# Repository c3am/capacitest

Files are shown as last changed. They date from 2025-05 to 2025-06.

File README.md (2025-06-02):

# capacitest
A low cost dual cell battery capacity tester with an oled screen using the ch32v003 microcontroller.

# discharge-tester (old version, unfinished)
In the discharge-tester directory is a pcb with mosfets used as variable resistors for discharging the cells.
It uses LMV358's as current sense amplifiers across 1 Ohm current sense resistors.
I did not get this setup to work, because the built-in adc gave me very jittery values.
Maybe there is something wrong with my circuit, or you just have to software filter the adc values.

# bidirectional-tester (current version, under development)
This is the newer version, which uses bidirectional buck-boost converters for charging the cells from an external ~12V battery/discharging them into that battery.

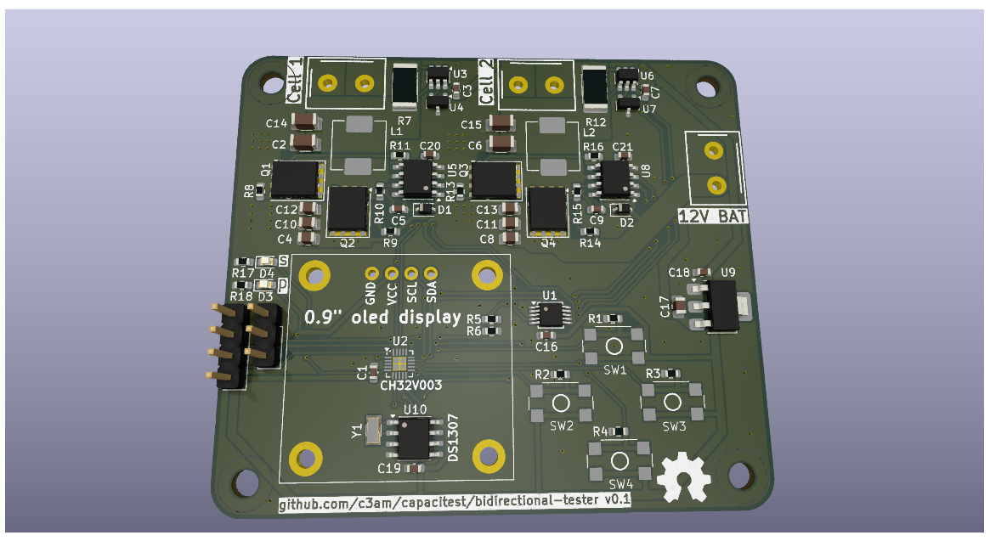
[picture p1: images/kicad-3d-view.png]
kicad 3d view of bidirectional tester


- ADS 1115 for current and voltage sensing
- ina181a2 + ref2020(2V Vref) for current sense amplification
- ir2101 low+high side mosfet drivers
- ceramic capacitors only
- the two bidirectional buck-/boost-converters each have 1uH SMD inductors, 200uF on the cell and 66uF capacitance on the ~12V battery side
- 0.9" i2c oled screen

## development status/roadmap:
| step | status |
| --- | --- |
| schematic design | [done] |
| PCB design | [done] |
| get PCB and other components  | [done] |
| assemble board | [...] |
| test board/write code | [not started] |
| if not working, repeat | |
| finalize code and put online  | [not started] |

(last updated: 2025-05-08)

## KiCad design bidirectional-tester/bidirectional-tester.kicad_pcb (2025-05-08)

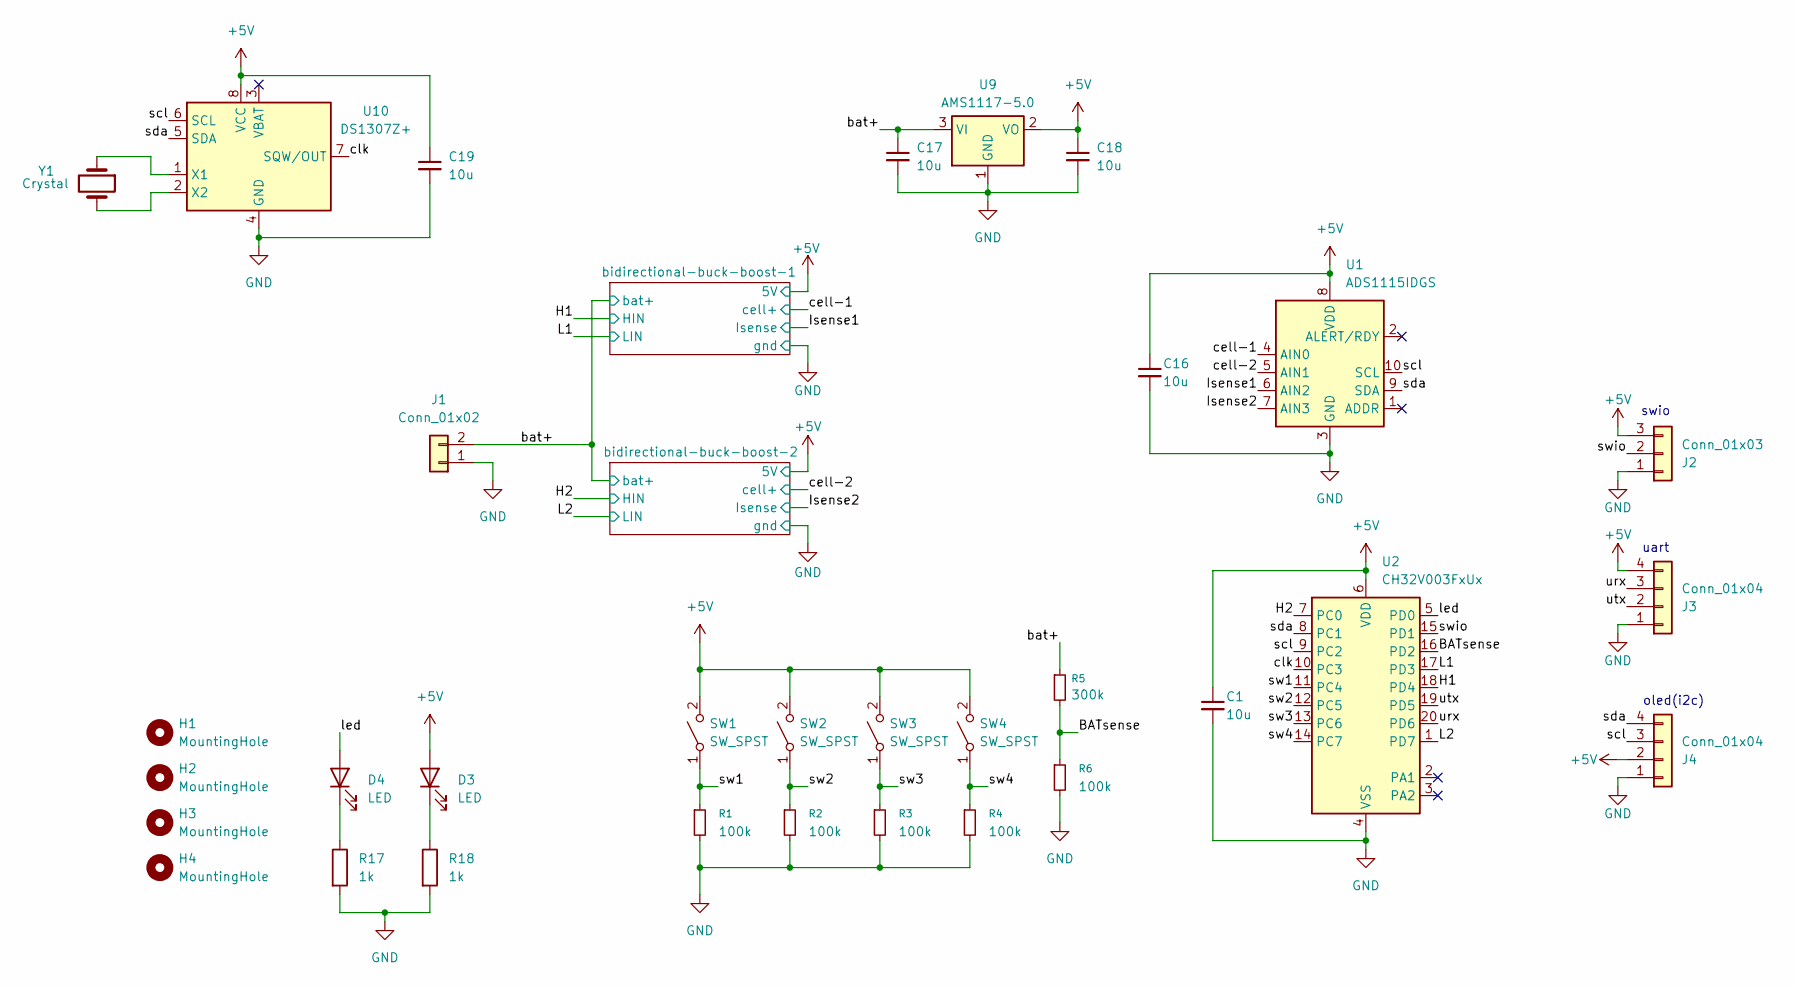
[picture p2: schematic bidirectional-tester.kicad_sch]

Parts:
C1, C16, C18, C19: 10u; C_0603_1608Metric
C17: 10u; C_0805_2012Metric
D3, D4: LED; LED_0603_1608Metric
H1, H2, H3, H4: MountingHole; MountingHole_3.2mm_M3
J1: Conn_01x02; screw-terminal_5mm_x2
J2: Conn_01x03; PinHeader_1x03_P2.54mm_Vertical
J3: Conn_01x04; PinHeader_1x04_P2.54mm_Vertical
J4: Conn_01x04; module-oled-0.9inch
R1, R2, R3, R4, R6: 100k; R_0603_1608Metric
R5: 300k; R_0603_1608Metric
R17, R18: 1k; R_0603_1608Metric
SW1, SW2, SW3, SW4: SW_SPST; switch
U1: ADS1115IDGS; TSSOP-10_3x3mm_P0.5mm
U2: CH32V003FxUx; QFN-20-1EP_3x3mm_P0.4mm_EP1.65x1.65mm
U9: AMS1117-5.0; SOT-223-3_TabPin2
U10: DS1307Z+; SOIC-8_3.9x4.9mm_P1.27mm
Y1: Crystal; Crystal_SMD_3215-2Pin_3.2x1.5mm

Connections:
+5V: C1.1, C16.1, C18.1, C19.1, D3.2 (A), J2.3, J3.4, J4.2, SW1.2 (B), SW2.2 (B), SW3.2 (B), SW4.2 (B), U1.8 (VDD), U2.6 (VDD), U9.2 (VO), U10.8 (VCC); also elsewhere on the board
/BATsense: R5.2, R6.1, U2.16 (PD2)
/H1: U2.18 (PD4); also elsewhere on the board
/H2: U2.7 (PC0); also elsewhere on the board
/Isense1: U1.6 (AIN2); also elsewhere on the board
/Isense2: U1.7 (AIN3); also elsewhere on the board
/L1: U2.17 (PD3); also elsewhere on the board
/L2: U2.1 (PD7); also elsewhere on the board
/bat+: C17.1, J1.2, R5.1, U9.3 (VI); also elsewhere on the board
/cell-1: U1.4 (AIN0); also elsewhere on the board
/cell-2: U1.5 (AIN1); also elsewhere on the board
/clk: U2.10 (PC3), U10.7 (SQW/OUT)
/led: D4.2 (A), U2.5 (PD0)
/scl: J4.3, U1.10 (SCL), U2.9 (PC2), U10.6 (SCL)
/sda: J4.4, U1.9 (SDA), U2.8 (PC1), U10.5 (SDA)
/sw1: R1.1, SW1.1 (A), U2.11 (PC4)
/sw2: R2.1, SW2.1 (A), U2.12 (PC5)
/sw3: R3.1, SW3.1 (A), U2.13 (PC6)
/sw4: R4.1, SW4.1 (A), U2.14 (PC7)
/swio: J2.2, U2.15 (PD1)
/urx: J3.3, U2.20 (PD6)
/utx: J3.2, U2.19 (PD5)
GND: C1.2, C16.2, C17.2, C18.2, C19.2, J1.1, J2.1, J3.1, J4.1, R1.2, R2.2, R3.2, R4.2, R6.2, R17.2, R18.2, U1.3 (GND), U2.4 (VSS), U2.21 (VSS), U9.1 (GND), U10.4 (GND); also elsewhere on the board
unnamed: D3.1 (K), R18.1
unnamed: D4.1 (K), R17.1
unnamed: U10.1 (X1), Y1.1
unnamed: U10.2 (X2), Y1.2

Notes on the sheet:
swio
oled(i2c)
uart

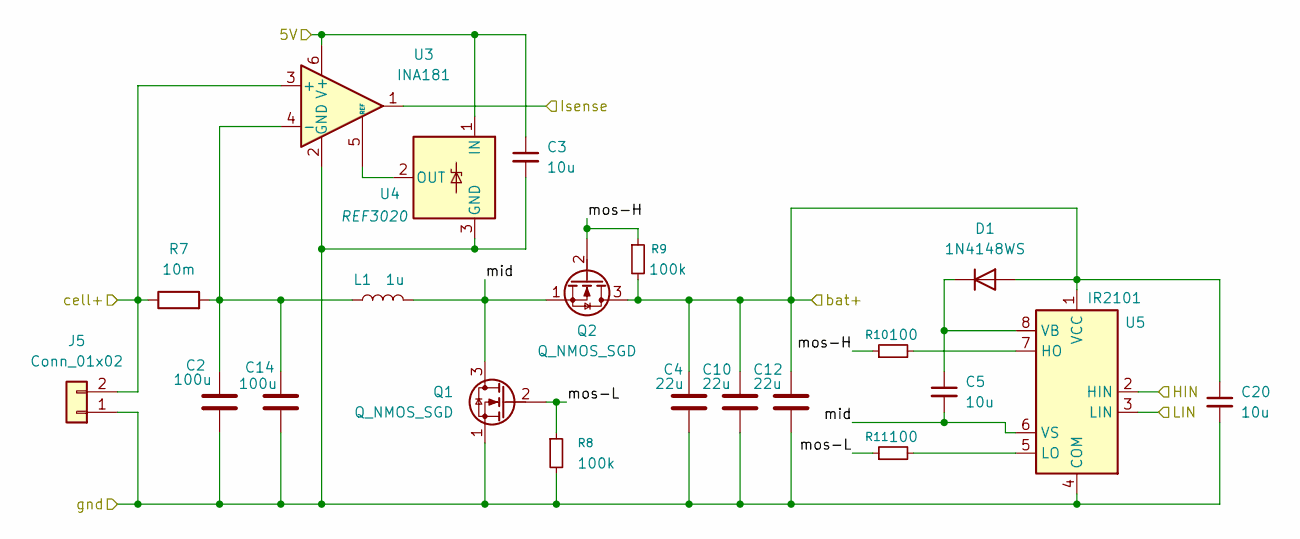
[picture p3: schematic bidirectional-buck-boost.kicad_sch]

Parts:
C2, C14: 100u; C_1206_3216Metric
C3, C5, C20: 10u; C_0603_1608Metric
C4, C10, C12: 22u; C_0805_2012Metric
D1: 1N4148WS; D_SOD-323
J5: Conn_01x02; screw-terminal_5mm_x2
L1: 1u; L_Changjiang_FXL0630
Q1, Q2: Q_NMOS_SGD; PQFN-8-EP_6x5mm_P1.27mm_Generic
R7: 10m; R_2512_6332Metric
R8, R9: 100k; R_0603_1608Metric
R10, R11: 100; R_0603_1608Metric
U3: INA181; SOT-23-6
U4: REF3020; SOT-23
U5: IR2101; SOIC-8_3.9x4.9mm_P1.27mm

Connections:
+5V: C3.1, U3.6 (V+), U4.1 (IN); also elsewhere on the board
/H1: U5.2 (HIN); also elsewhere on the board
/Isense1: U3.1; also elsewhere on the board
/L1: U5.3 (LIN); also elsewhere on the board
/bat+: C4.1, C10.1, C12.1, C20.1, D1.2 (A), Q2.3 (D), R9.2, U5.1 (VCC); also elsewhere on the board
/bidirectional-buck-boost-1/mid: C5.2, L1.2, Q1.3 (D), Q2.1 (S), U5.6 (VS)
/bidirectional-buck-boost-1/mos-H: Q2.2 (G), R9.1, R10.1
/bidirectional-buck-boost-1/mos-L: Q1.2 (G), R8.1, R11.1
/cell-1: J5.2, R7.1, U3.3 (+); also elsewhere on the board
GND: C2.2, C3.2, C4.2, C10.2, C12.2, C14.2, C20.2, J5.1, Q1.1 (S), R8.2, U3.2 (GND), U4.3 (GND), U5.4 (COM); also elsewhere on the board
unnamed: C5.1, D1.1 (K), U5.8 (VB)
unnamed: C2.1, C14.1, L1.1, R7.2, U3.4 (-)
unnamed: U3.5 (REF), U4.2 (OUT)
unnamed: R10.2, U5.7 (HO)
unnamed: R11.2, U5.5 (LO)

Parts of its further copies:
C6, C15: 100u; C_1206_3216Metric
C7, C9, C21: 10u; C_0603_1608Metric
C8, C11, C13: 22u; C_0805_2012Metric
D2: 1N4148WS; D_SOD-323
J6: Conn_01x02; screw-terminal_5mm_x2
L2: 1u; L_Changjiang_FXL0630
Q3, Q4: Q_NMOS_SGD; PQFN-8-EP_6x5mm_P1.27mm_Generic
R12: 10m; R_2512_6332Metric
R13, R14: 100k; R_0603_1608Metric
R15, R16: 100; R_0603_1608Metric
U6: INA181; SOT-23-6
U7: REF3020; SOT-23
U8: IR2101; SOIC-8_3.9x4.9mm_P1.27mm

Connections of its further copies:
+5V: C7.1, U6.6 (V+), U7.1 (IN); also elsewhere on the board
/H2: U8.2 (HIN); also elsewhere on the board
/Isense2: U6.1; also elsewhere on the board
/L2: U8.3 (LIN); also elsewhere on the board
/bat+: C8.1, C11.1, C13.1, C21.1, D2.2 (A), Q4.3 (D), R14.2, U8.1 (VCC); also elsewhere on the board
/bidirectional-buck-boost-2/mid: C9.2, L2.2, Q3.3 (D), Q4.1 (S), U8.6 (VS)
/bidirectional-buck-boost-2/mos-H: Q4.2 (G), R14.1, R15.1
/bidirectional-buck-boost-2/mos-L: Q3.2 (G), R13.1, R16.1
/cell-2: J6.2, R12.1, U6.3 (+); also elsewhere on the board
GND: C6.2, C7.2, C8.2, C11.2, C13.2, C15.2, C21.2, J6.1, Q3.1 (S), R13.2, U6.2 (GND), U7.3 (GND), U8.4 (COM); also elsewhere on the board
unnamed: C9.1, D2.1 (K), U8.8 (VB)
unnamed: C6.1, C15.1, L2.1, R12.2, U6.4 (-)
unnamed: U6.5 (REF), U7.2 (OUT)
unnamed: R15.2, U8.7 (HO)
unnamed: R16.2, U8.5 (LO)

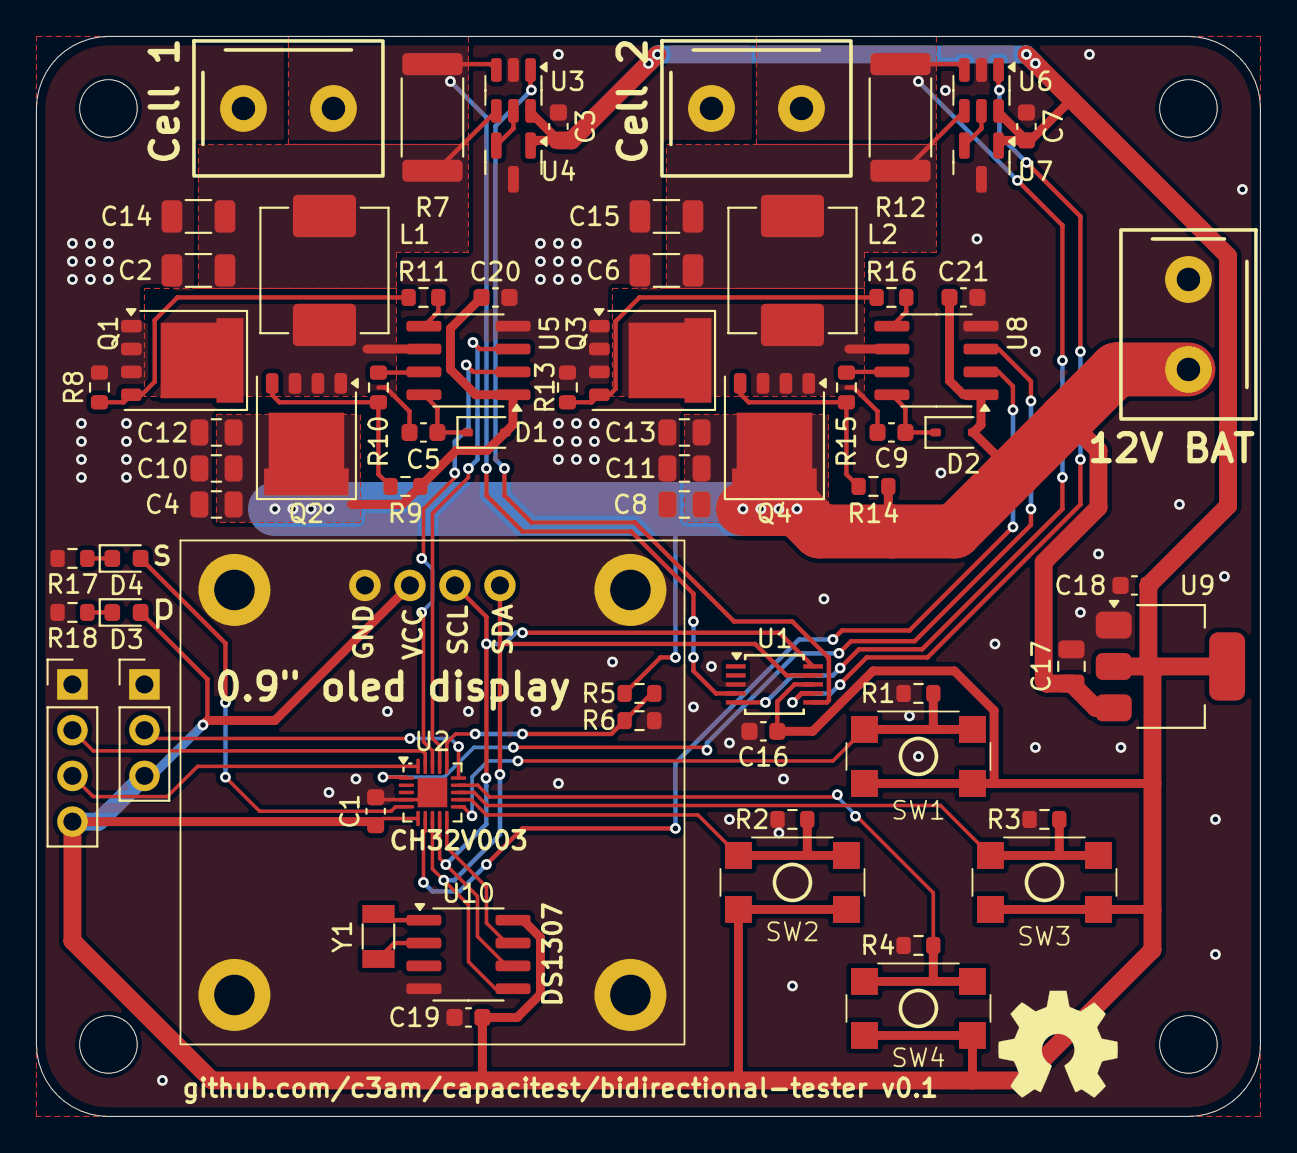
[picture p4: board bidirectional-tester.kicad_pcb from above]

Board: 2 copper layers, 68.0 x 60.0 mm, 74 parts (0 on the bottom side), 43 nets.

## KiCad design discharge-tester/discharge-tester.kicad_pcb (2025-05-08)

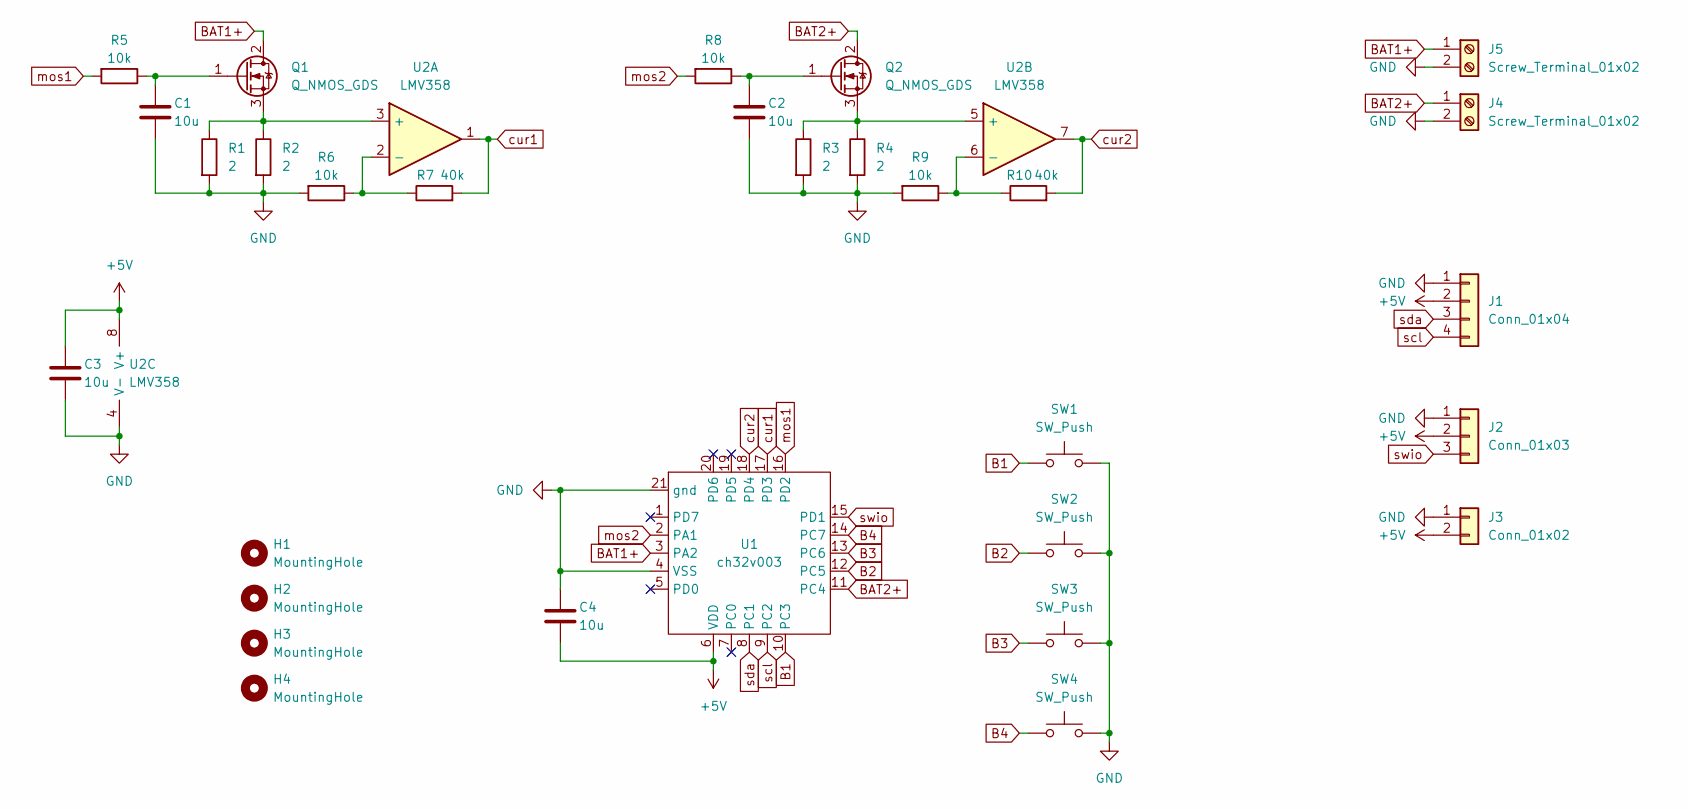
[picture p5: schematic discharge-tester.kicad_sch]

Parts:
C1, C2, C3, C4: 10u; C_0603_1608Metric
H1, H2, H3, H4: MountingHole; MountingHole_3.2mm_M3
J1: Conn_01x04; module-oled-0.96
J2: Conn_01x03; pin-header-2.5mm-3
J3: Conn_01x02; pin-header-2.5mm-2
J4, J5: Screw_Terminal_01x02; screw-terminal-P5.00mm-1x02
Q1, Q2: Q_NMOS_GDS; TO-252-2
R1, R2, R3, R4: 2; R_2512_6332Metric
R5, R6, R8, R9: 10k; R_0603_1608Metric
R7, R10: 40k; R_0603_1608Metric
SW1, SW2, SW3, SW4: SW_Push; sw-4.5mm
U1: ch32v003; QFN-20-1EP_3x3mm_P0.4mm_EP1.65x1.65mm
U2: LMV358; SOP-8_3.9x4.9mm_P1.27mm

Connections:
+5V: C3.1, C4.2, J1.2, J2.2, J3.2, U1.6 (VDD), U2.8 (V+)
B1: SW1.1, U1.10 (PC3)
B2: SW2.1, U1.12 (PC5)
B3: SW3.1, U1.13 (PC6)
B4: SW4.1, U1.14 (PC7)
BAT1+: J5.1, Q1.2 (D), U1.3 (PA2)
BAT2+: J4.1, Q2.2 (D), U1.11 (PC4)
GND: C1.2, C2.2, C3.2, C4.1, J1.1, J2.1, J3.1, J4.2, J5.2, R1.2, R2.2, R3.2, R4.2, R6.2, R9.2, SW1.2, SW2.2, SW3.2, SW4.2, U1.4 (VSS), U1.21 (gnd), U2.4 (V-)
unnamed: C1.1, Q1.1 (G), R5.1
unnamed: Q1.3 (S), R1.1, R2.1, U2.3 (+)
unnamed: C2.1, Q2.1 (G), R8.1
unnamed: Q2.3 (S), R3.1, R4.1, U2.5 (+)
unnamed: R6.1, R7.1, U2.2 (-)
unnamed: R9.1, R10.1, U2.6 (-)
cur1: R7.2, U1.17 (PD3), U2.1
cur2: R10.2, U1.18 (PD4), U2.7
mos1: R5.2, U1.16 (PD2)
mos2: R8.2, U1.2 (PA1)
scl: J1.4, U1.9 (PC2)
sda: J1.3, U1.8 (PC1)
swio: J2.3, U1.15 (PD1)

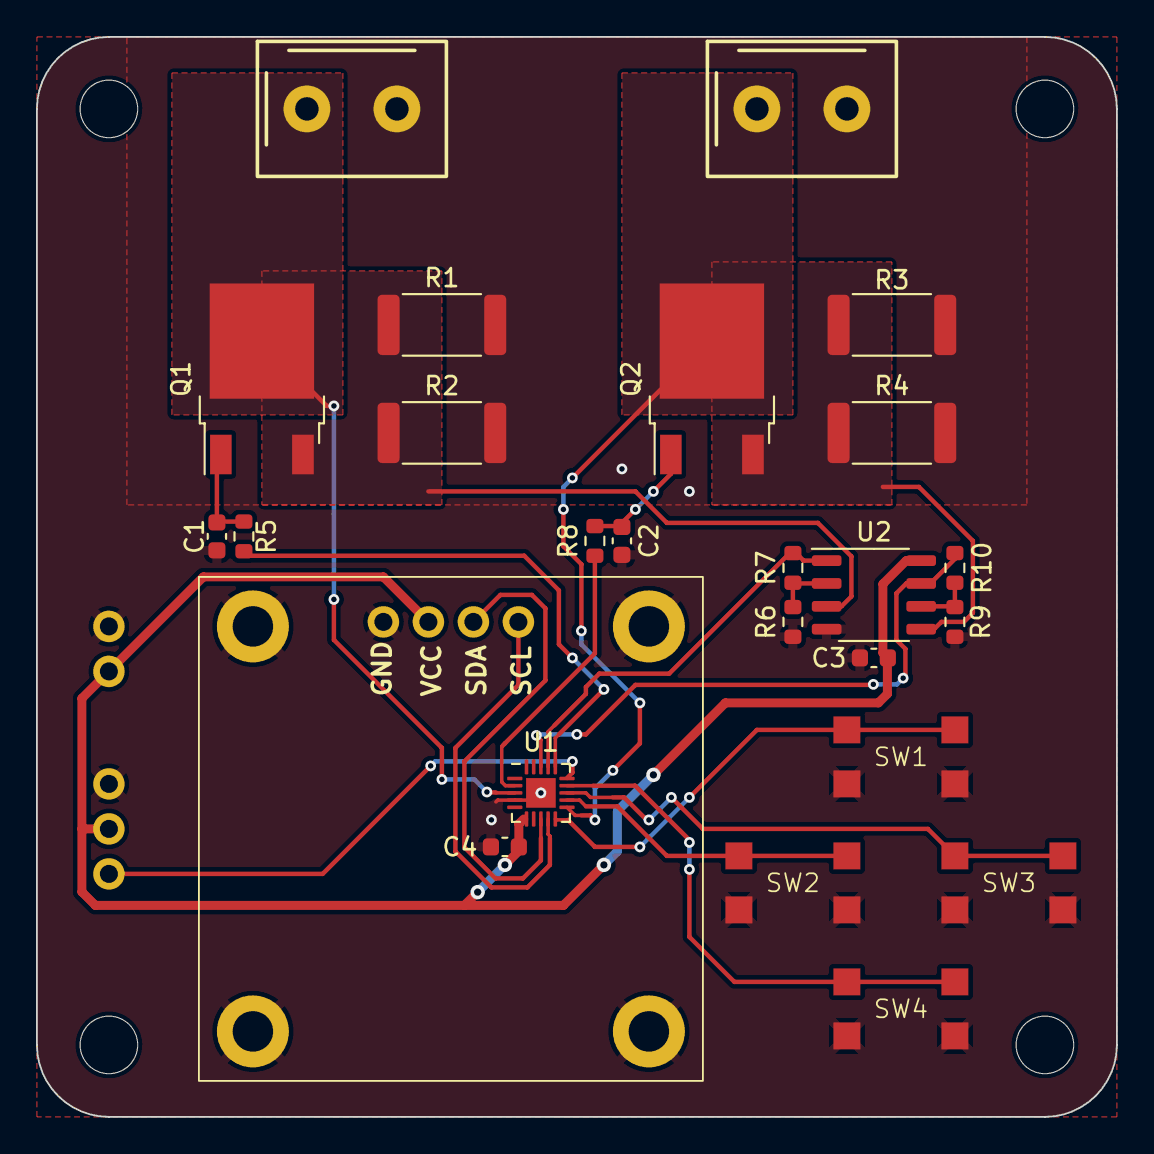
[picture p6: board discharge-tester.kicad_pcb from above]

Board: 2 copper layers, 60.0 x 60.0 mm, 31 parts (0 on the bottom side), 21 nets.

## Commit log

2023-12-02 upload initial project files
    [discharge-tester.kicad_pcb, discharge-tester.kicad_sch]
2025-05-08 version 0.1
    [bidirectional-buck-boost.kicad_sch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]
2025-05-08 removed unnecessary cad files
2025-05-08 added silkscreen screw terminal descriptions
    [bidirectional-tester.kicad_pcb]
2025-05-08 removed output files, will be releases in the future
    [bidirectional-tester-B_Cu.gbl, bidirectional-tester-B_Mask.gbs, bidirectional-tester-B_Paste.gbp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]
2025-05-08 added indicator leds
    [bidirectional-tester.kicad_pcb, bidirectional-tester.kicad_sch]
2025-05-08 added indicator leds 2 cause it didnt work
2025-05-08 added indicator leds 3 lol
